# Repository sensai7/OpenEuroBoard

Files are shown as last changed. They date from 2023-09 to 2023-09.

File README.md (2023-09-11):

# OpenEuroBoard
Kicad and Gerber files for the manufacturing of electronic synthesizers prototyping and developing, focusing on utilities to prototype Eurorack modules. All the sections in the board are independent from each other (except the Gate/CV generators) that need the 5V regulator part, and can be disregarded if they're not needed for the user application.

Board

Board
(This is from an older version but the features are the same)

## Feature List:
 * Size adjusted to fit exactly a standard sized breadboard.
 * SSD1306 driver based Screen interfaces, with sockets for both 128x64px and 128x32px versions.
 * 2x quad op-amps (TL074) for custom use.
 * 5V regulator and power bus.
 * 4x custom push buttons.
 * MIDI IN/OUT interfaces. MIDI IN is isolated through a optocoupler, MIDI OUT is buffered.
 * 8x custom Minijack sockets.
 * 5x pots, 2x custom pots to connect any desired value. The pots can be easily shorted to ground, +12V, or between their own pins using a jumper.
 * 4x custom SPDT switches.
 * 4x custom LEDs.
 * Small jumper storage.
 * A stereo buffered out with a stereo minijack socket.
 * Custom test points and power bus test points.
 * 2x Gate and CV generators, Both signals being 0~5V.
 * 2x oscillators with low (LFO) and high (Audio rate) range switches and frequency pots.
 * Screw mount holes

## Bill Of Materials:
|Section |Type |Model |Amount|
|---|---|---|---|
|General |Male Header |2x5 dupont header |2 |
| |Female Header |1x40 dupont header |2 |
| |Voltage regulator|LM1117-5 |1 |
| |LED |3mm Red LED |1 |
| |Resistor |2.2k |1 |
| |Capacitor |100n |2 |
| |Elec. Capacitor  |10u |4 |
|Screen interfaces|Screen |SSD1306 |1 |
|quad op-amps |Op. amp |TL074 |2 |
| |Capacitor |100n |4 |
|Push buttons |Push button |6mm push |4 |
|MIDI IN-OUT |Din-5 Connector  |Din-5 Connector |2 |
| |Optocoupler |6n139 |1 |
| |Dual inverter |CD40107BE |1 |
| |Diode |1n4148 |1 |
| |Resistor |220 |3 |
| |Resistor |270 |1 |
| |Resistor |120 |2 |
|Minijack sockets |Minijack |Thonkiconn jack |8 |
|Potentiometer |Potentiometer |Alps vertical pot |5 |
|Switches |SPDT |8.5mm SPDT |4 |
|LEDS |LED |3mm Red LED |4 |
| |Resistor |1k |4 |
|Jumper storage |Jumper |2.54mm jumper |5 |
|Stereo out |Op. amp |TL072 |1 |
| |Capacitor |100n |2 |
| |Minijack |Vertical stereo jack |1 |
|Gate generators  |Push button |6mm push |2 |
| |Resistor |4.7k |2 |
|CV Generators |Potentiometer |Alps vertical pot 100k  |2 |
|Oscillators |Op. amp |Tl074 |1 |
| |Capacitor |100n |4 |
| |Potentiometer |Alps vertical pot 1M LOG|2 |
| |SPDT |8.5mm SPDT |2 |
| |Capacitor |1u |2 |
| |Capacitor |22n |2 |
| |Resistor |1k |4 |
| |Resistor |10k |4 |
| |Resistor |100k |2 |

## Changelog

 * V1.0 First version
 * V1.1 Addressed the issues from [Issue 1](https://github.com/sensai7/OpenEuroBoard/issues/1). Updated Silkscreen

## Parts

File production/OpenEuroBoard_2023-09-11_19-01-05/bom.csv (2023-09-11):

Designator | Footprint | Quantity | Value | LCSC Part #
C1 | CP_Radial_D4.0mm_P2.00mm | 1 | 100u
C10, C6, C9 | CP_Radial_D4.0mm_P2.00mm | 3 | 10u
C11, C12 | C_Disc_D3.4mm_W2.1mm_P2.50mm | 2 | 22n
C13, C14 | C_Disc_D3.4mm_W2.1mm_P2.50mm | 2 | 1u
C15, C16, C17, C18, C19, C2, C20, C3, C4, C5, C7, C8 | C_Disc_D3.4mm_W2.1mm_P2.50mm | 12 | 100n
D1, D2, D3, D4, D5 | LED_D3.0mm_FlatTop | 5 | LED
D6 | D_DO-35_SOD27_P7.62mm_Horizontal | 1 | 1N4148
J1 | Eurorack_mini_bus | 1 | Eurorack_bus_mini
J10 | Jack_3.5mm_QingPu_WQP-PJ398SM_Vertical_CircularHoles | 1 | Jack 4
J11, J27, J28, J57, J8 | PinHeader_1x08_P2.54mm_Vertical | 5 | Conn_01x08
J12 | Jack_3.5mm_QingPu_WQP-PJ398SM_Vertical_CircularHoles | 1 | Jack 5
J13 | Jack_3.5mm_QingPu_WQP-PJ398SM_Vertical_CircularHoles | 1 | Jack 6
J14 | Jack_3.5mm_QingPu_WQP-PJ398SM_Vertical_CircularHoles | 1 | Jack 7
J15 | Jack_3.5mm_QingPu_WQP-PJ398SM_Vertical_CircularHoles | 1 | Jack 8
J16, J29, J46, J53, J56 | PinHeader_1x04_P2.54mm_Vertical | 5 | Conn_01x04
J17 | din-5 | 1 | MIDI_in
J18, J19, J20, J22, J24, J26, J32, J34, J36, J40, J41, J43, J44 | PinHeader_1x03_P2.54mm_Vertical | 13 | Conn_01x03
J2, J3, J4, J5 | PinHeader_1x07_P2.54mm_Vertical | 4 | Conn_01x07
J21 | din-5 | 1 | MIDI_out
J23, J25, J31, J33, J35, J39, J42 | PinHeader_1x05_P2.54mm_Vertical | 7 | Conn_01x05
J30, J37, J38, J47, J48, J49, J50, J51 | MountingHole_3.2mm_M3_Pad_Via | 8 | Screw_Terminal_01x01
J45 | PinSocket_1x02_P2.54mm_Vertical | 1 | Conn_01x02
J52, J54 | 0.91 inches 128x32 Screen | 2 | Conn_01x04
J55 | PinHeader_2x05_P2.54mm_Vertical | 1 | Jumpers
J58 | PinHeader_1x02_P2.54mm_Vertical | 1 | Conn_01x02
J59 | Jack Stereo vertical Thonk | 1 | AudioJack3_Ground
J6 | Jack_3.5mm_QingPu_WQP-PJ398SM_Vertical_CircularHoles | 1 | Jack 1
J7 | Jack_3.5mm_QingPu_WQP-PJ398SM_Vertical_CircularHoles | 1 | Jack 2
J9 | Jack_3.5mm_QingPu_WQP-PJ398SM_Vertical_CircularHoles | 1 | Jack 3
R1 | R_Axial_DIN0207_L6.3mm_D2.5mm_P7.62mm_Horizontal | 1 | 2.2k
R10, R9 | R_Axial_DIN0207_L6.3mm_D2.5mm_P7.62mm_Horizontal | 2 | 120
R11, R13, R8 | R_Axial_DIN0207_L6.3mm_D2.5mm_P7.62mm_Horizontal | 3 | 220
R12 | R_Axial_DIN0207_L6.3mm_D2.5mm_P7.62mm_Horizontal | 1 | 270
R14, R15, R16, R17 | R_Axial_DIN0207_L6.3mm_D2.5mm_P7.62mm_Horizontal | 4 | 10k
R18, R19, R20, R21, R4, R5, R6, R7 | R_Axial_DIN0207_L6.3mm_D2.5mm_P7.62mm_Horizontal | 8 | 1k
R2, R3 | R_Axial_DIN0207_L6.3mm_D2.5mm_P7.62mm_Horizontal | 2 | 4.7k
RV1, RV11, RV2, RV9 | trimmer_alps-rk09k1130ah1 | 4 | 100k
RV10 | trimmer_alps-rk09k1130ah1 | 1 | 1k
RV3 | trimmer_alps-rk09k1130ah1 | 1 | 1M
RV4, RV5 | trimmer_alps-rk09k1130ah1 | 2 | 1M LOG
RV6 | trimmer_alps-rk09k1130ah1 | 1 | 10k
SW1, SW2, SW3, SW4, SW5, SW6 | SW_PUSH_6mm_H5mm | 6 | SW_Push
SW10, SW11, SW12, SW7, SW8, SW9 | SPDT_8.5x3.7mm_SS12d00G4 | 6 | SW_SPDT
TP1, TP2, TP3, TP4, TP5, TP6, TP7, TP8 | TestPoint_THTPad_D3.0mm_Drill1.5mm | 8 | TestPoint
U1 | TO-220-3_Horizontal_TabDown | 1 | LM1117IMP-5
U2, U3, U6 | DIP-14_W7.62mm_Socket_LongPads | 3 | TL074
U4 | DIP-8_W7.62mm_LongPads | 1 | CD40107BE
U5 | DIP-8_W7.62mm | 1 | 6N139
U7 | DIP-8_W7.62mm_Socket_LongPads | 1 | TL072
U8 | DIP-14_W7.62mm | 1 | TL074

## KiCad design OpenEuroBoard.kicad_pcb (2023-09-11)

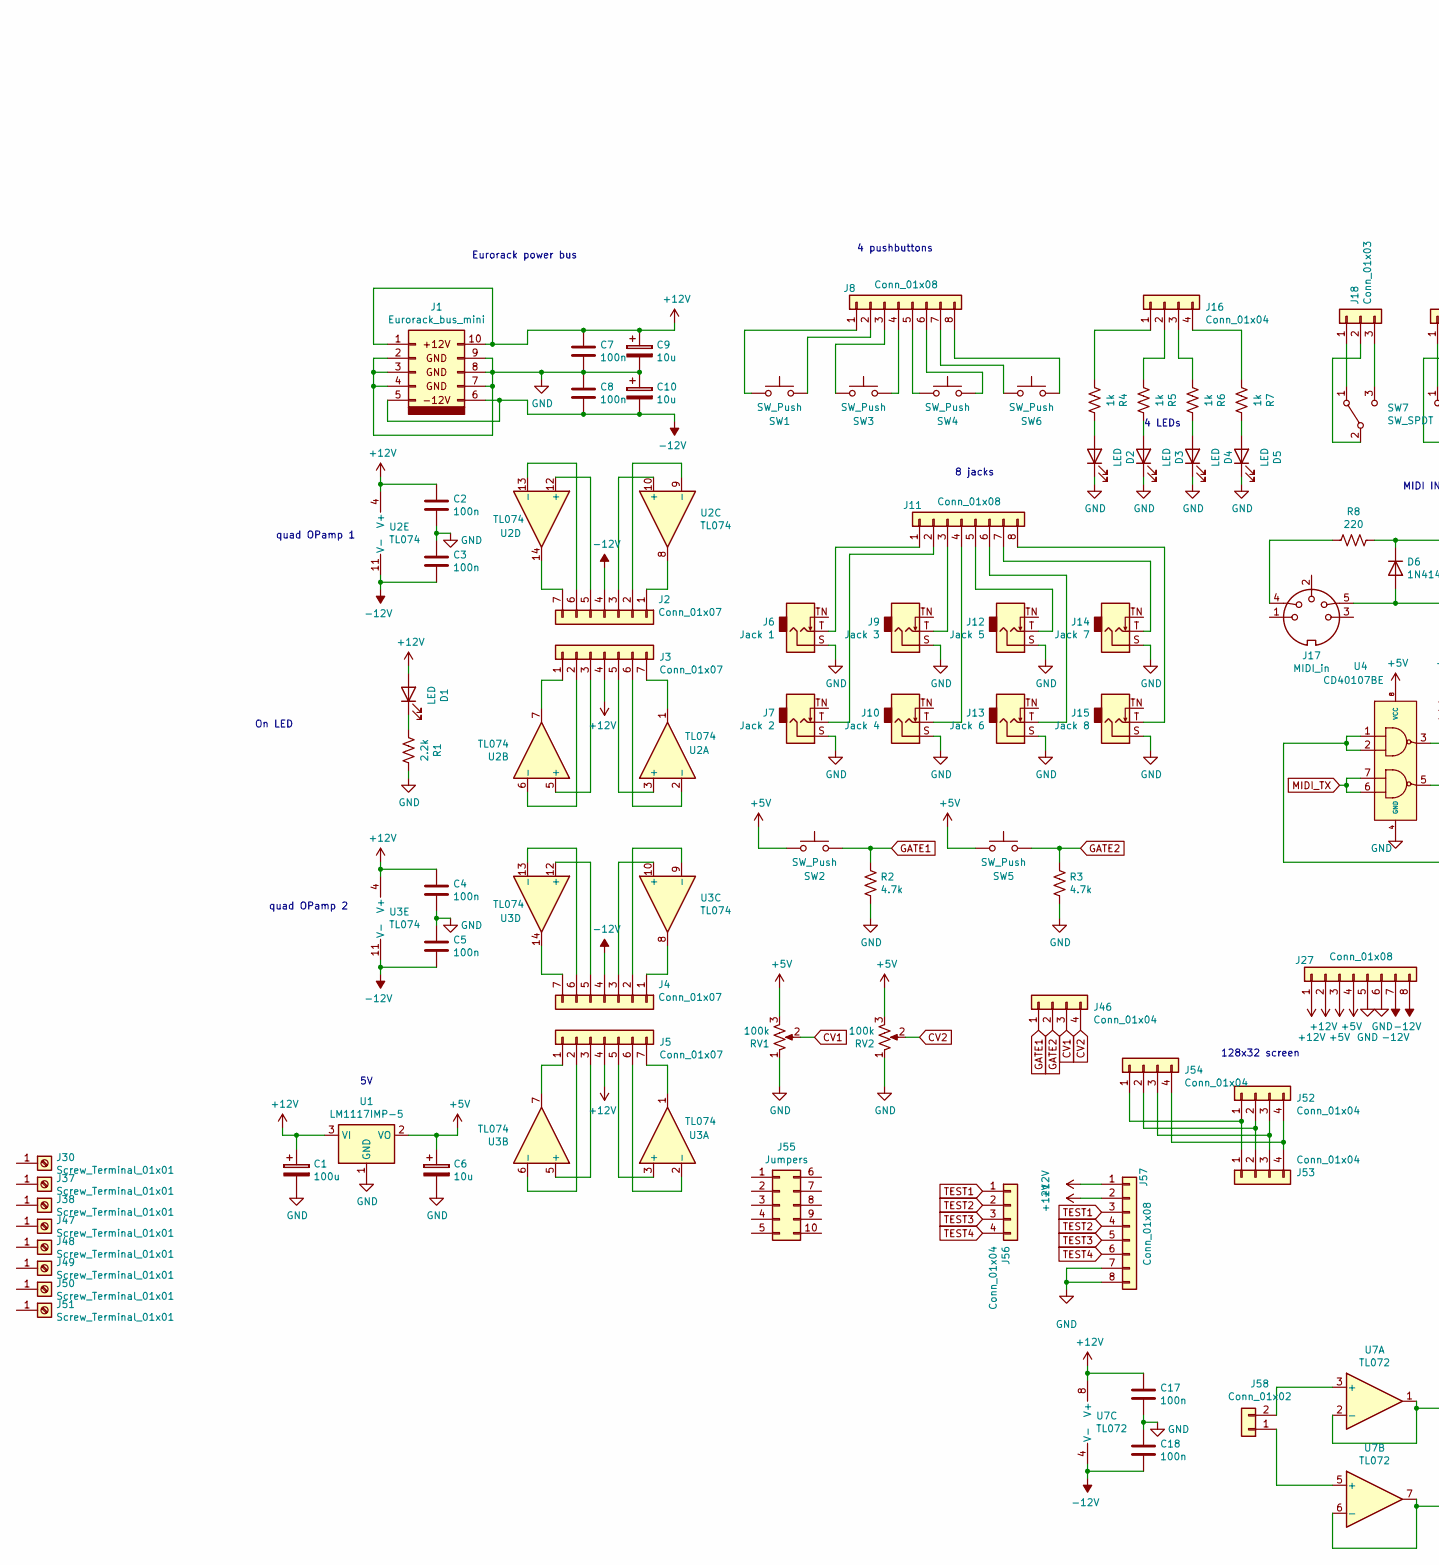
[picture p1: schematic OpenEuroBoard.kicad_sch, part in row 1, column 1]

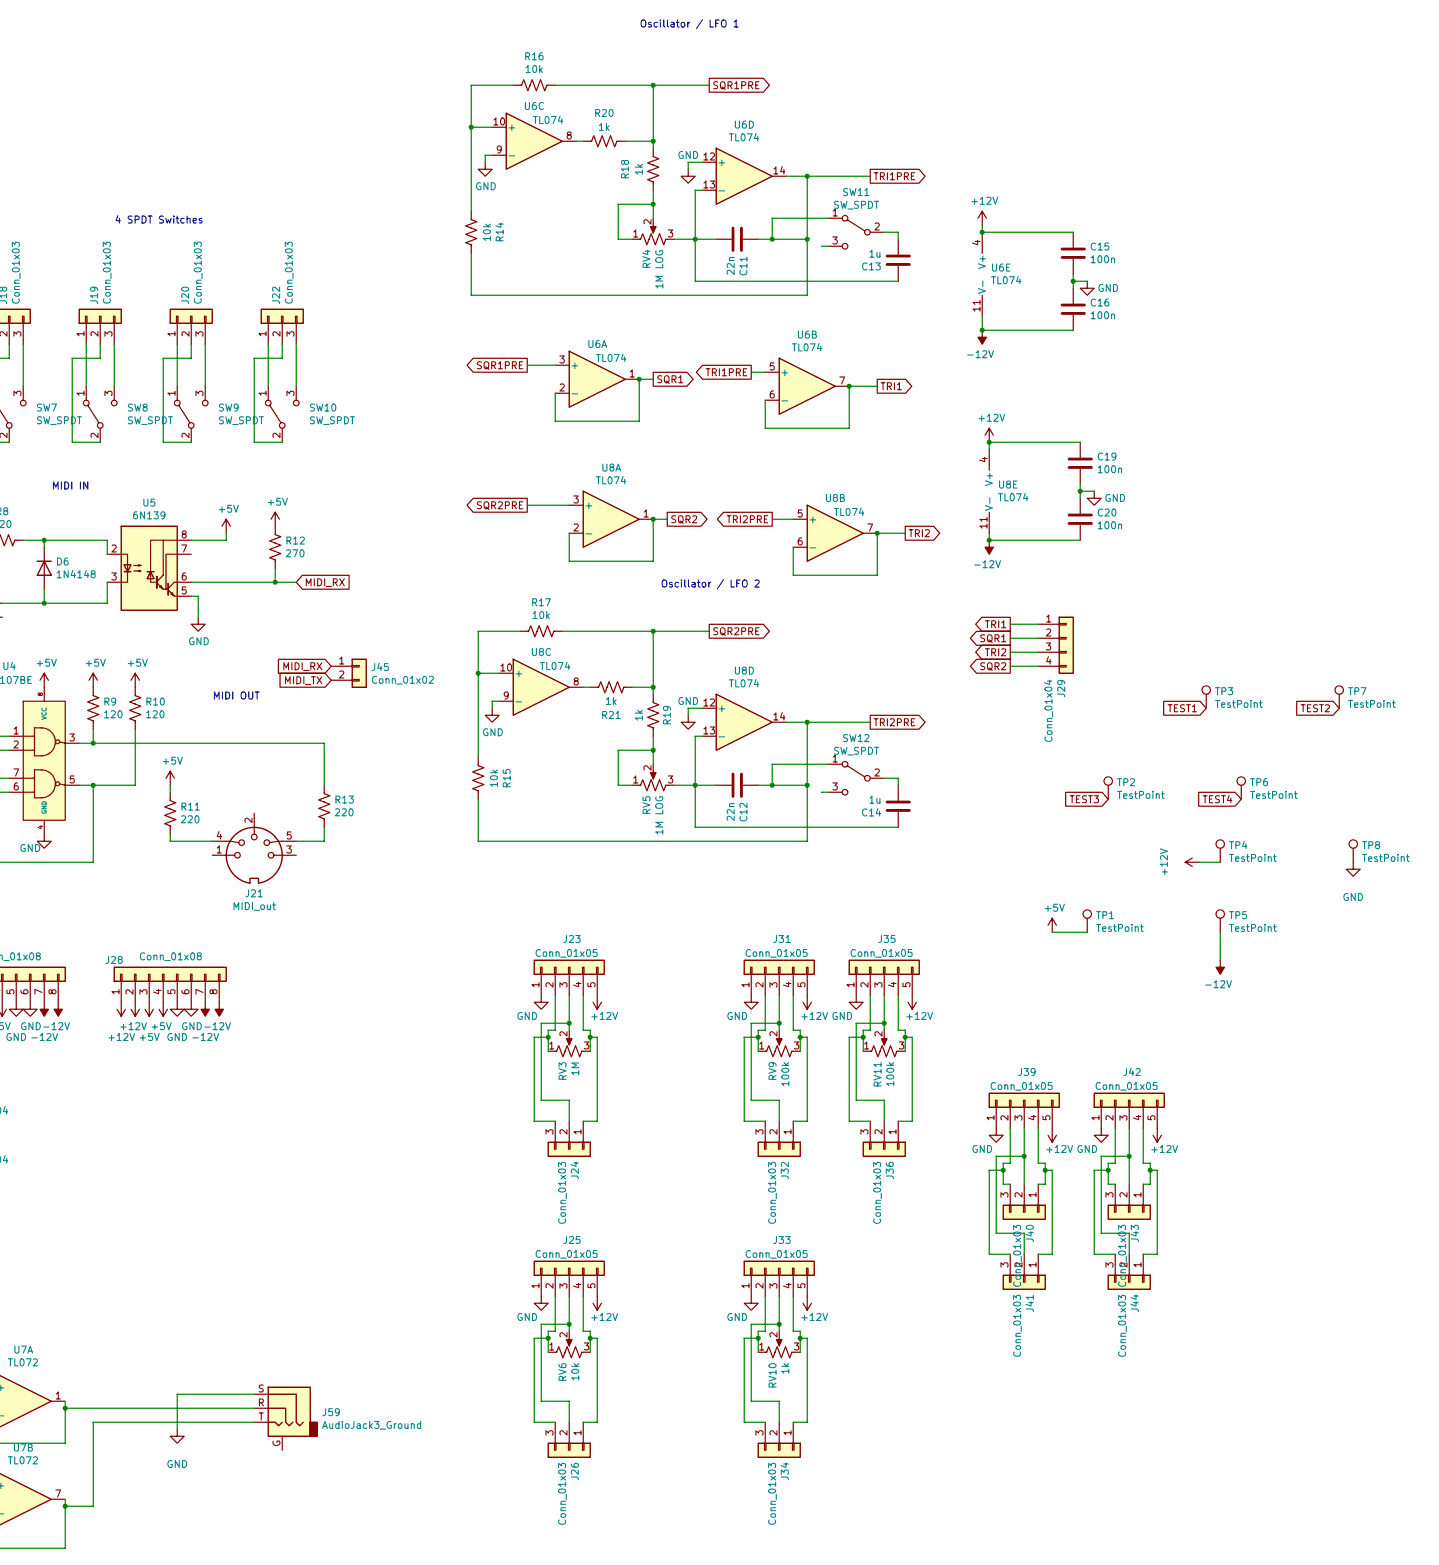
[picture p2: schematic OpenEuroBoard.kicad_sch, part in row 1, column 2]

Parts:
C1: 100u; CP_Radial_D4.0mm_P2.00mm
C2, C3, C4, C5, C7, C8, C15, C16, C17, C18, C19, C20: 100n; C_Disc_D3.4mm_W2.1mm_P2.50mm
C6, C9, C10: 10u; CP_Radial_D4.0mm_P2.00mm
C11, C12: 22n; C_Disc_D3.4mm_W2.1mm_P2.50mm
C13, C14: 1u; C_Disc_D3.4mm_W2.1mm_P2.50mm
D1, D2, D3, D4, D5: LED; LED_D3.0mm_FlatTop
D6: 1N4148; D_DO-35_SOD27_P7.62mm_Horizontal
J1: Eurorack_bus_mini; Eurorack_mini_bus
J2, J3, J4, J5: Conn_01x07; PinHeader_1x07_P2.54mm_Vertical
J6: Jack 1; Jack_3.5mm_QingPu_WQP-PJ398SM_Vertical_CircularHoles
J7: Jack 2; Jack_3.5mm_QingPu_WQP-PJ398SM_Vertical_CircularHoles
J8, J11, J27, J28, J57: Conn_01x08; PinHeader_1x08_P2.54mm_Vertical
J9: Jack 3; Jack_3.5mm_QingPu_WQP-PJ398SM_Vertical_CircularHoles
J10: Jack 4; Jack_3.5mm_QingPu_WQP-PJ398SM_Vertical_CircularHoles
J12: Jack 5; Jack_3.5mm_QingPu_WQP-PJ398SM_Vertical_CircularHoles
J13: Jack 6; Jack_3.5mm_QingPu_WQP-PJ398SM_Vertical_CircularHoles
J14: Jack 7; Jack_3.5mm_QingPu_WQP-PJ398SM_Vertical_CircularHoles
J15: Jack 8; Jack_3.5mm_QingPu_WQP-PJ398SM_Vertical_CircularHoles
J16, J29, J46, J53, J56: Conn_01x04; PinHeader_1x04_P2.54mm_Vertical
J17: MIDI_in; din-5
J18, J19, J20, J22, J24, J26, J32, J34, J36, J40, J41, J43, J44: Conn_01x03; PinHeader_1x03_P2.54mm_Vertical
J21: MIDI_out; din-5
J23, J25, J31, J33, J35, J39, J42: Conn_01x05; PinHeader_1x05_P2.54mm_Vertical
J30, J37, J38, J47, J48, J49, J50, J51: Screw_Terminal_01x01; MountingHole_3.2mm_M3_Pad_Via
J45: Conn_01x02; PinSocket_1x02_P2.54mm_Vertical
J52, J54: Conn_01x04; 0.91 inches 128x32 Screen
J55: Jumpers; PinHeader_2x05_P2.54mm_Vertical
J58: Conn_01x02; PinHeader_1x02_P2.54mm_Vertical
J59: AudioJack3_Ground; Jack Stereo vertical Thonk
R1: 2.2k; R_Axial_DIN0207_L6.3mm_D2.5mm_P7.62mm_Horizontal
R2, R3: 4.7k; R_Axial_DIN0207_L6.3mm_D2.5mm_P7.62mm_Horizontal
R4, R5, R6, R7, R18, R19, R20, R21: 1k; R_Axial_DIN0207_L6.3mm_D2.5mm_P7.62mm_Horizontal
R8, R11, R13: 220; R_Axial_DIN0207_L6.3mm_D2.5mm_P7.62mm_Horizontal
R9, R10: 120; R_Axial_DIN0207_L6.3mm_D2.5mm_P7.62mm_Horizontal
R12: 270; R_Axial_DIN0207_L6.3mm_D2.5mm_P7.62mm_Horizontal
R14, R15, R16, R17: 10k; R_Axial_DIN0207_L6.3mm_D2.5mm_P7.62mm_Horizontal
RV1, RV2, RV9, RV11: 100k; trimmer_alps-rk09k1130ah1
RV3: 1M; trimmer_alps-rk09k1130ah1
RV4, RV5: 1M LOG; trimmer_alps-rk09k1130ah1
RV6: 10k; trimmer_alps-rk09k1130ah1
RV10: 1k; trimmer_alps-rk09k1130ah1
SW1, SW2, SW3, SW4, SW5, SW6: SW_Push; SW_PUSH_6mm_H5mm
SW7, SW8, SW9, SW10, SW11, SW12: SW_SPDT; SPDT_8.5x3.7mm_SS12d00G4
TP1, TP2, TP3, TP4, TP5, TP6, TP7, TP8: TestPoint; TestPoint_THTPad_D3.0mm_Drill1.5mm
U1: LM1117IMP-5; TO-220-3_Horizontal_TabDown
U2, U3: TL074
U4: CD40107BE; DIP-8_W7.62mm_LongPads
U5: 6N139; DIP-8_W7.62mm
U6, U8: TL074; DIP-14_W7.62mm
U7: TL072; DIP-8_W7.62mm_Socket_LongPads

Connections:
+5V: C6.1, J27.3, J27.4, J28.3, J28.4, R9.1, R10.1, R11.1, R12.1, RV1.3, RV2.3, SW2.1, SW5.1, TP1.1, U1.2 (VO), U4.8 (VCC), U5.8 (VCC)
+12V: C1.1, C2.1, C4.1, C7.1, C9.1, C15.1, C17.1, C19.1, D1.2 (A), J1.1, J1.10, J3.4, J5.4, J23.5, J25.5, J27.1, J27.2, J28.1, J28.2, J31.5, J33.5, J35.5, J39.5, J42.5, J57.1, J57.2, TP4.1, U1.3 (VI), U2.4 (V+), U3.4 (V+), U6.4 (V+), U7.8 (V+), U8.4 (V+)
-12V: C3.2, C5.2, C8.2, C10.2, C16.2, C18.2, C20.2, J1.5, J1.6, J2.4, J4.4, J27.7, J27.8, J28.7, J28.8, TP5.1, U2.11 (V-), U3.11 (V-), U6.11 (V-), U7.4 (V-), U8.11 (V-)
CV1: J46.3, RV1.2
CV2: J46.4, RV2.2
GATE1: J46.1, R2.1, SW2.2
GATE2: J46.2, R3.1, SW5.2
GND: C1.2, C2.2, C3.1, C4.2, C5.1, C6.2, C7.2, C8.1, C9.2, C10.1, C15.2, C16.1, C17.2, C18.1, C19.2, C20.1, D2.1 (K), D3.1 (K), D4.1 (K), D5.1 (K), J1.2, J1.3, J1.4, J1.7, J1.8, J1.9, J6.S, J7.S, J9.S, J10.S, J12.S, J13.S, J14.S, J15.S, J23.1, J25.1, J27.5, J27.6, J28.5, J28.6, J31.1, J33.1, J35.1, J39.1, J42.1, J57.7, J57.8, J59.S, R1.1, R2.2, R3.2, RV1.1, RV2.1, TP8.1, U1.1 (GND), U4.4 (GND), U5.5 (GND), U6.9 (-), U6.12 (+), U8.9 (-), U8.12 (+)
MIDI_RX: J45.1, R12.2, U5.6 (VO2)
MIDI_TX: J45.2, U4.6, U4.7
unnamed: D1.1 (K), R1.2
unnamed: D2.2 (A), R4.1
unnamed: D3.2 (A), R5.1
unnamed: D4.2 (A), R6.1
unnamed: D5.2 (A), R7.1
unnamed: D6.2 (A), J17.5, U5.3 (C2)
unnamed: D6.1 (K), R8.1, U5.2 (C1)
unnamed: J2.1, U2.8
unnamed: J2.2, U2.9 (-)
unnamed: J2.3, U2.10 (+)
unnamed: J2.5, U2.12 (+)
unnamed: J2.6, U2.13 (-)
unnamed: J2.7, U2.14
unnamed: J3.1, U2.7
unnamed: J3.2, U2.6 (-)
unnamed: J3.3, U2.5 (+)
unnamed: J3.5, U2.3 (+)
unnamed: J3.6, U2.2 (-)
unnamed: J3.7, U2.1
unnamed: J4.1, U3.8
unnamed: J4.2, U3.9 (-)
unnamed: J4.3, U3.10 (+)
unnamed: J4.5, U3.12 (+)
unnamed: J4.6, U3.13 (-)
unnamed: J4.7, U3.14
unnamed: J5.1, U3.7
unnamed: J5.2, U3.6 (-)
unnamed: J5.3, U3.5 (+)
unnamed: J5.5, U3.3 (+)
unnamed: J5.6, U3.2 (-)
unnamed: J5.7, U3.1
unnamed: J8.1, SW1.1
unnamed: J8.2, SW1.2
unnamed: J8.3, SW3.1
unnamed: J8.4, SW3.2
unnamed: J8.5, SW4.1
unnamed: J8.6, SW4.2
unnamed: J8.7, SW6.1
unnamed: J8.8, SW6.2
unnamed: J6.T, J11.1
unnamed: J7.T, J11.2
unnamed: J9.T, J11.3
unnamed: J10.T, J11.4
unnamed: J11.5, J12.T
unnamed: J11.6, J13.T
unnamed: J11.7, J14.T
unnamed: J11.8, J15.T
unnamed: J16.1, R4.2
unnamed: J16.2, R5.2
unnamed: J16.3, R6.2
unnamed: J16.4, R7.2
unnamed: J17.4, R8.2
unnamed: J18.1, SW7.1 (A)
unnamed: J18.2, SW7.2 (B)
unnamed: J18.3, SW7.3 (C)
unnamed: J19.1, SW8.1 (A)
unnamed: J19.2, SW8.2 (B)
unnamed: J19.3, SW8.3 (C)
unnamed: J20.1, SW9.1 (A)
unnamed: J20.2, SW9.2 (B)
unnamed: J20.3, SW9.3 (C)
unnamed: J21.4, R11.2
unnamed: J21.5, R13.2
unnamed: J22.1, SW10.1 (A)
unnamed: J22.2, SW10.2 (B)
unnamed: J22.3, SW10.3 (C)
unnamed: J23.2, J24.3, RV3.1
unnamed: J23.3, J24.2, RV3.2
unnamed: J23.4, J24.1, RV3.3
unnamed: J25.2, J26.3, RV6.1
unnamed: J25.3, J26.2, RV6.2
unnamed: J25.4, J26.1, RV6.3
unnamed: J31.2, J32.3, RV9.1
unnamed: J31.3, J32.2, RV9.2
unnamed: J31.4, J32.1, RV9.3
unnamed: J33.2, J34.3, RV10.1
unnamed: J33.3, J34.2, RV10.2
unnamed: J33.4, J34.1, RV10.3
unnamed: J35.2, J36.3, RV11.1
unnamed: J35.3, J36.2, RV11.2
unnamed: J35.4, J36.1, RV11.3
unnamed: J39.2, J40.3, J41.3
unnamed: J39.3, J40.2, J41.2
unnamed: J39.4, J40.1, J41.1
unnamed: J42.2, J43.3, J44.3
unnamed: J42.3, J43.2, J44.2
unnamed: J42.4, J43.1, J44.1
unnamed: J52.1, J53.1, J54.1
unnamed: J52.2, J53.2, J54.2
unnamed: J52.3, J53.3, J54.3
unnamed: J52.4, J53.4, J54.4
unnamed: J58.1, U7.5 (+)
unnamed: J58.2, U7.3 (+)
unnamed: R10.2, U4.1, U4.2, U4.5
unnamed: R9.2, R13.1, U4.3
unnamed: R18.1, RV4.1, RV4.2
unnamed: R19.1, RV5.1, RV5.2
unnamed: R20.1, U6.8
unnamed: R21.2, U8.8
unnamed: C13.2, SW11.2 (B)
unnamed: C14.2, SW12.2 (B)
unnamed: R14.2, R16.2, U6.10 (+)
unnamed: C11.2, C13.1, RV4.3, U6.13 (-)
unnamed: J59.R, U7.1, U7.2 (-)
unnamed: J59.T, U7.6 (-), U7.7
unnamed: R15.2, R17.2, U8.10 (+)
unnamed: C12.2, C14.1, RV5.3, U8.13 (-)
SQR1: J29.2, U6.1, U6.2 (-)
SQR1PRE: R16.1, R18.2, R20.2, U6.3 (+)
SQR2: J29.4, U8.1, U8.2 (-)
SQR2PRE: R17.1, R19.2, R21.1, U8.3 (+)
TEST1: J56.1, J57.3, TP3.1
TEST2: J56.2, J57.4, TP7.1
TEST3: J56.3, J57.5, TP2.1
TEST4: J56.4, J57.6, TP6.1
TRI1: J29.1, U6.6 (-), U6.7
TRI1PRE: C11.1, R14.1, SW11.1 (A), U6.5 (+), U6.14
TRI2: J29.3, U8.6 (-), U8.7
TRI2PRE: C12.1, R15.1, SW12.1 (A), U8.5 (+), U8.14

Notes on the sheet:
4 pushbuttons
MIDI OUT
8 jacks
quad OPamp 1
4 SPDT Switches
128x32 screen
Eurorack power bus
quad OPamp 2
Oscillator / LFO 2
MIDI IN
4 LEDs
Oscillator / LFO 1
On LED

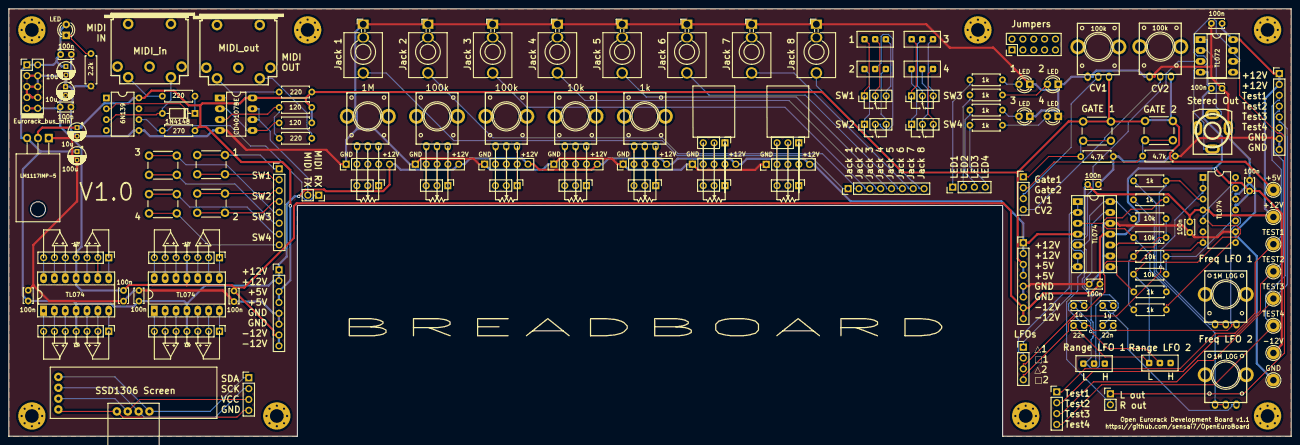
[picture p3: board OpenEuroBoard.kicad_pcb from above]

Board: 2 copper layers, 300.0 x 100.0 mm, 143 parts (0 on the bottom side), 129 nets.

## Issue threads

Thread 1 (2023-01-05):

Various issues

guytaylor, 2023-01-05:
I just built two of these are there seem to be some problems.

Not too serious:
1. CV1 and CV2 pots are backwards. CCW = 5V, CW =0V
2. BOM states 7805 for the regulator but this doesn't work, needs to be LM1117-5 (as printed on PCB)
3. LFO 1 is output on LFO 2 pins, and LFO 2 is output on LFO 1 pins

Serious:
4. LFO doesn't appear to work properly. Square wave out does work (but needs buffering if going to euro), but triangle output has no output (I connected it to the LED, it does one cycle and then halts) (I tried numerous different TL074, and TL084 and TL064, All behaved the same on both units)

DRnooberson, 2023-09-09:
@guytaylor Got the exact same issues as you. Did you have any luck finding a fix for #4 ? These LFO could be very useful for circuit design if they worked properly.

sensai7, 2023-09-10:
Sorry for neglecting this issue for so long. I've been testing the LFO circuit and found a solution. The oscillator needs a load resistor from the square output to ground so the triangle wave swings all the way. This is something ECAD softwares don't seem to need, but in the real-world circuit a 1k resistor from the sqr output of the LFO to ground does the trick. You can use that as a makeshift fix for the board. it 100% needs a buffer after adding the load resistor.

I'll be updating the git files in the following days addressing all (1~4) issues

guytaylor, 2023-09-11:
No worries, thanks for the update.
I just tested it, and it's working fine now. Thanks :)

DRnooberson, 2023-09-15:
Thanks a lot for the support @sensai7 ! This worked like a charm

Closed 2023-09-11.

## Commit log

2020-08-06 Initial commit for real
    [OpenEuroBoard.kicad_pcb, OpenEuroBoard.sch]
2020-08-16 Silkscreen and general rework
    [OpenEuroBoard.kicad_pcb, OpenEuroBoard.sch]
2020-08-30 Finished layout, silkscreen and routing
    also fixed minijack footprint
    [OpenEuroBoard.kicad_pcb, OpenEuroBoard.sch]
2020-08-30 finished silkscreen, fixed some minor errors
    [OpenEuroBoard.kicad_pcb]
2021-01-10 Added BOM
2021-01-10 Added Gerber files
    [OpenEuroBoard-B.Cu.gbr, OpenEuroBoard-B.Mask.gbr, OpenEuroBoard-B.Paste.gbr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]
2023-09-11 Version 1.1
    [OpenEuroBoard-B.Cu.gbr, OpenEuroBoard-B.Mask.gbr, OpenEuroBoard-B.Paste.gbr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]
